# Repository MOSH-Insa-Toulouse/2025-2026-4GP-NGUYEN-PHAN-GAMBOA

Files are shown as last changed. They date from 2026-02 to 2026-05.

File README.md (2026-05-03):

# Projet : Capteur en Graphite
## Context
Ce projet a été réalisé dans le cadre du cours « Du capteur au banc de test », durant le deuxième semestre de l’année universitaire 2025–2026, au sein de la formation de 4ᵉ année en Génie Physique. Il s’appuie sur l’article scientifique « Pencil Drawn Strain Gauges and Chemiresistors on Paper » de Cheng-Wei Lin, Zhibo Zhao, Jaemyung Kim et Jiaxing Huang, qui étudie les propriétés du graphite et démontre son potentiel en tant que matériau sensible pouvant être utilisé comme capteur de déformation.

L’idée principale de ce projet est de concevoir un capteur de déformation low-tech, inspiré de cette publication, en utilisant uniquement une feuille de papier et une couche de graphite d'un crayon déposée par simple tracé.

L’objectif est d’évaluer les performances, la fiabilité de ce capteur à faible coût et de vérifier s’il peut être commercialisé.
## Sommaire
- [Context](#context)
- [Sommaire](#sommaire)
- [Principe de fonctionnement du capteur en graphite](#principe-de-fonctionnement-du-capteur-en-graphite)
- [Réalisation du projet](#réalisation-du-projet)
  - [Matériaux nécessaire](#matériaux-nécessaire)
  - [Simulation électronique sur LTSpice](#simulation-électronique-sur-ltspice)
  - [Conception PCB avec KiCad](#conception-pcb-avec-kiCad)
  - [Réalisation du Shield](#réalisation-du-shield)
  - [Code Arduino](#code-arduino)
  - [Conception application sur MIT App Inventor](#conception-application-sur-mit-app-inventor)
  - [Bancs de test](#bancs-de-test)
    - [Sensibilité](#sensibilité)
    - [Répétabilité](#répétabilité)
- [Datasheet](#datasheet)
- [Conclusion](#conclusion)

## Principe de fonctionnement du capteur en graphite
<div align="center">
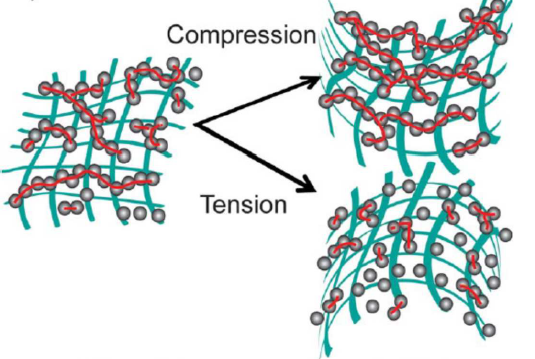
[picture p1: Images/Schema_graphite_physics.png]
  
  <br/>
  <em>Figure 1: Principe de fonctionnement du capteur graphite en traction et en compression</em>
</div>
  <br/>

La mine de crayon est déposée sur le papier de manière mécanique. Elle pénètre dans la structure poreuse du papier et forme une piste conductrice composée de particules de graphite mélangées à un liant isolant, comme l’argile. Ces particules créent un réseau conducteur à l’intérieur des fibres du papier. Quand le papier est soumis à une contrainte mécanique, ce réseau change : sous traction, les contacts entre les particules diminuent, tandis que sous compression, ils augmentent. Ces modifications provoquent alors des variations mesurables de la résistance électrique.

## Réalisation du projet
Afin d’atteindre les objectifs fixés, le travail a été divisé en deux tâches principales : 

1. la mesure de la résistance du capteur en graphite et son affichage via une interface

2. la réalisation de bancs de test pour évaluer l’efficacité de ce capteur
<div align="center">
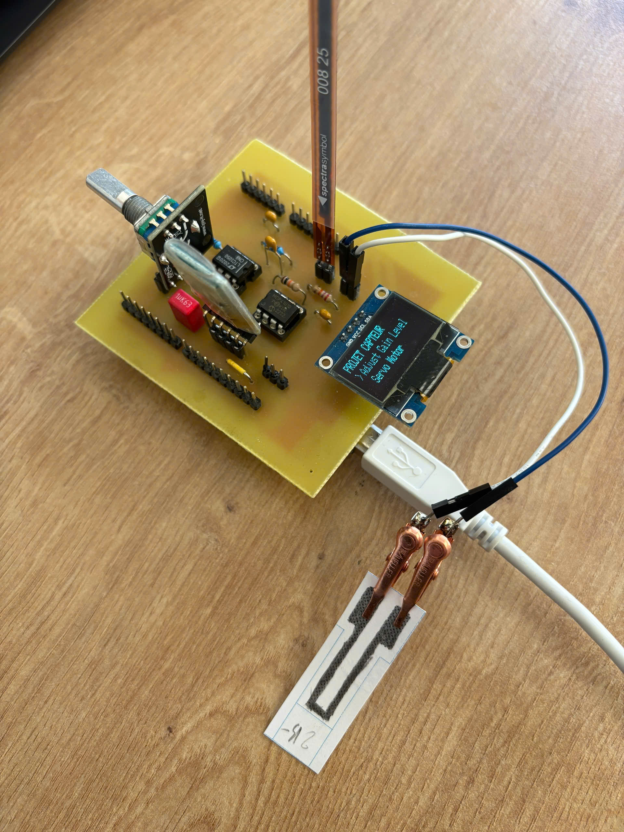
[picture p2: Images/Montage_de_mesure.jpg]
  
  <br/>
  <em>Figure 2: Montage expérimental de mesure du capteur graphite</em>
</div>

### Matériaux nécessaire
Pour réaliser le shield, nous avons besoin du matériel suivant :

* 1 carte Arduino UNO Rev 3
* 1 module Bluetooth (HC-05)
* 1 encodeur rotatif (KY-040)
* 1 écran OLED (Joy-it SBC-OLED01)
* 1 capteur de flexion commercial (Spectra Symbol Flex Sensors 005 21)
* 1 capteur en graphite fabriqués de la mine d'un crayon de papier
* 1 amplificateur (LTC1050)
* 1 potentiomètre numérique (MCP41010)
* 1 résistance 1kΩ, 1 résistance 10kΩ, 2 résistances 100kΩ et 1 résistance 27kΩ
* 3 condensateurs 100nF, 1 condensateur 1µF
* 2 supports IC pour le potentiomètre et l'amplificateur
* Pin headers (male et female)

Pour les bancs de test :
* 1 modèle 3D à diamètres variables
* 1 servomoteur (Parallax standard servo)

### Simulation électronique sur LTSpice
Dans le cas réel, la résistance du capteur en graphite est très élevée, ce qui conduit à un courant très faible, de l’ordre de 100 à 150 nA. Dans ces conditions, une mesure directe de la résistance à l’aide d’un multimètre n’est pas optimale.
Nous avons donc choisi de mesurer ce faible courant à l’aide d’un microcontrôleur. L’Arduino Uno a été retenu car il est open source, simple à utiliser, et bénéficie d’une large communauté, ce qui nous rend plus facile pour une première approche des microcontrôleurs.

En raison du courant très faible fourni par le capteur, nous avons utilisé un amplificateur transimpédance pour transformer ce courant en une tension mesurable par l’Arduino. Le gain du circuit peut être modifié simplement en changeant la valeur de la résistance R2.

Pour limiter le bruit, en particulier le bruit du réseau électrique à 50 Hz, trois filtres passe‑bas ont été ajoutés. Ces filtres permettent aussi de s’assurer que le signal en sortie du circuit est compatible avec la fréquence d’acquisition de l’Arduino.

<div align="center">
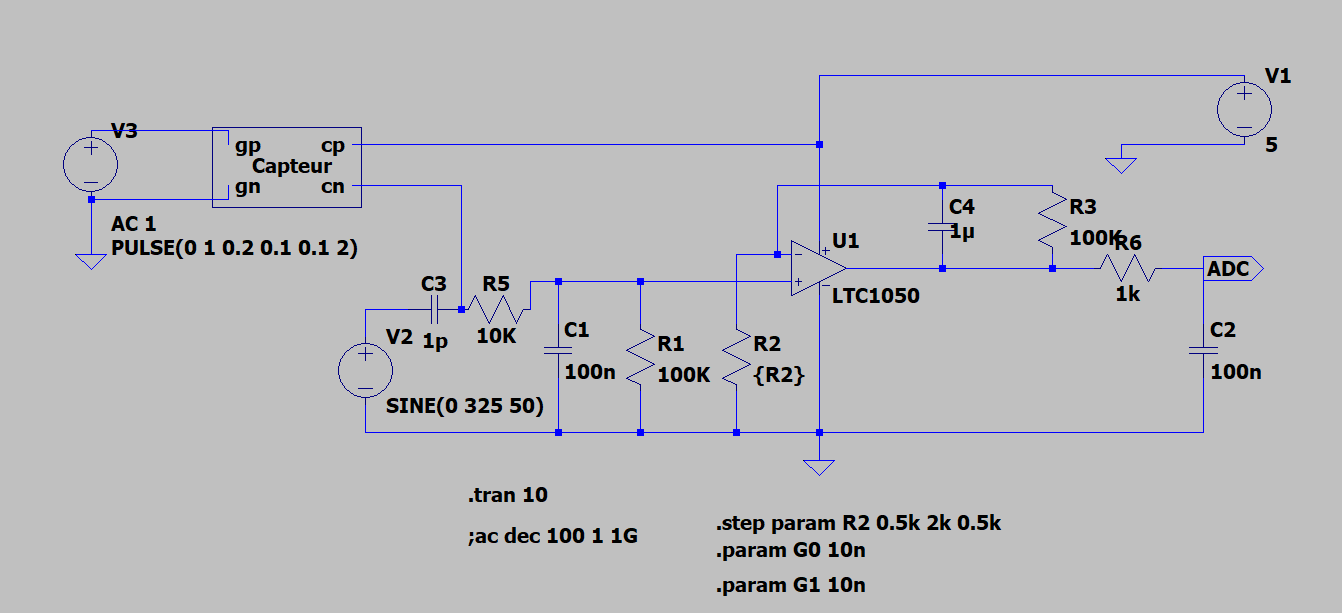
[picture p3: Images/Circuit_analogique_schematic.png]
  
  <br/>
  <em>Figure 3: Circuit d’amplification et de filtrage du signal</em>
</div>  
  <br/>

<table width="100%">
  <tr>
    <td width="50%" align="center">
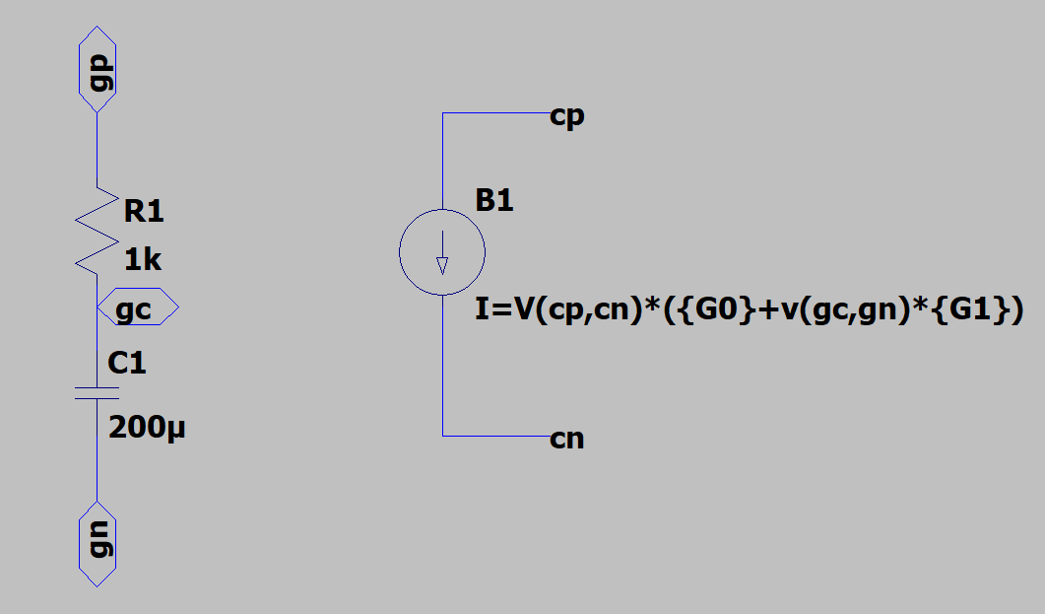
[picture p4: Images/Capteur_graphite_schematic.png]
      <br>
      <em>Figure 4: Modèle électrique du capteur graphite</em>
    </td>
    <td width="50%" align="center">
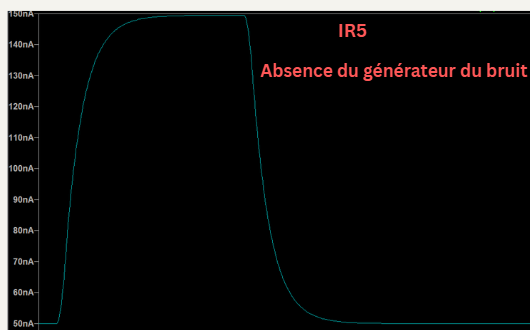
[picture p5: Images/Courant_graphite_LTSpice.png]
      <br>
      <em>Figure 5: Courant du capteur graphite simulé sous LTSpice (sans bruit)</em>
    </td>
  </tr>
</table>

Pour la simulation, le capteur graphite réel est modélisé dans LTSpice par un circuit électronique dans le figure 4, qui produit une sortie de courant d’environ 150 nA conformément à la valeur réalité (Figure 5). Le sous‑ensemble C3, R5 et le générateur V2 permet de simuler les bruits provenant de l’environnement.

<table>
  <tr>
    <td align="center">
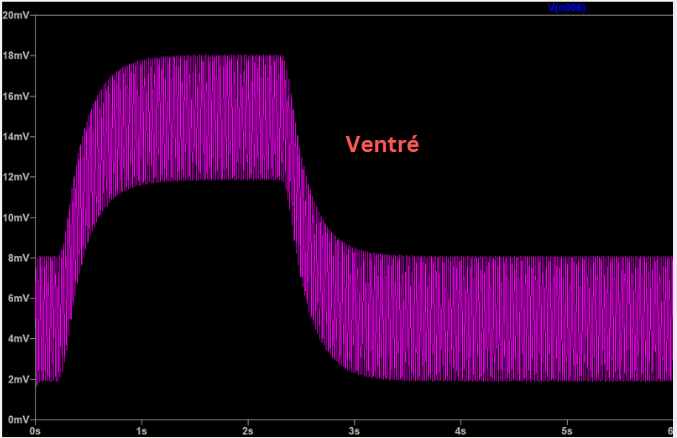
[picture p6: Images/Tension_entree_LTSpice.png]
Hình 1
      
      <br/>
      <em>Figure 6: Tension d’entrée du circuit d'amplificateur simulée sous LTSpice</em>
    </td>
    <td align="center">
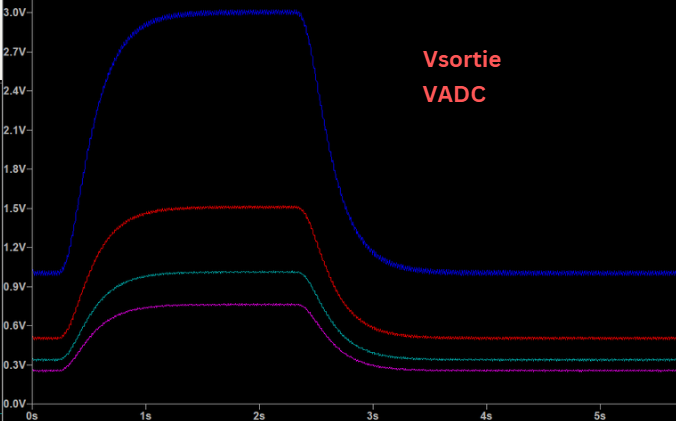
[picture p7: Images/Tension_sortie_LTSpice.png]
Hình 2
      
      <br/>
     <em>Figure 7: Tension de sortie du circuit (V_ADC) simulée sous LTSpice</em>
    </td>
  </tr>
</table>

Les simulations montrent une tension d’entrée du circuit d’environ 18 mV avant filtrage et amplification (Figure 6). En sortie, le signal est correctement amplifié et filtré, comme illustré sur la figure correspondante 7. Le niveau d’amplification obtenu dépend directement de la valeur choisie pour R2.

### Conception PCB avec KiCad
Après avoir vérifié que le circuit électronique proposé fonctionnait correctement sous LTSpice, nous avons commencé la conception du shield Arduino avec KiCad.

Le shield intègre l’ensemble des éléments nécessaires à notre projet :

- un circuit analogique pour l’amplification et le filtrage du signal du capteur graphite 
- un potentiomètre numérique pour régler le gain du signal 
- un encodeur rotatif permettant de naviguer dans les menus 
- un écran OLED pour afficher les informations et les fonctions du système 
- un module Bluetooth pour la communication avec l’application Android 
- un servomoteur utilisé dans les bancs de test 
- un capteur flex, utilisé comme référence pour comparer les performances avec le capteur graphite
<div align="center">
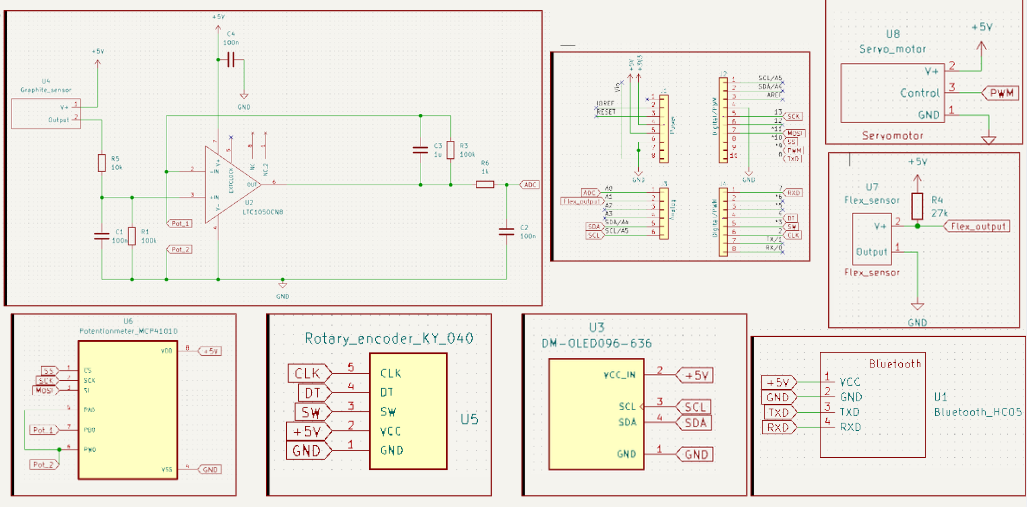
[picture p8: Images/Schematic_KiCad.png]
  
  <br/>
  <em>Figure 8: Schéma électronique global du système sous KiCad</em>
</div>  
  <br/>

Une fois tous les schémas électroniques réalisés et correctement connectés, nous avons effectué le routage du PCB. Pendant le routage, nous avons pris soin de bien connecter les masses et de tracer les pistes afin d’éviter les interférences. Enfin, un seul via sur la face avant a été utilisé pour faciliter le routage.

La dernière étape est de générer la vue 3D du shield final. Il permet de vérifier la disposition des composants, de s’assurer qu’il n’y a pas de chevauchement et que l’espace disponible est suffisant avant la fabrication du PCB.

<table>
  <tr>
    <td align="center">
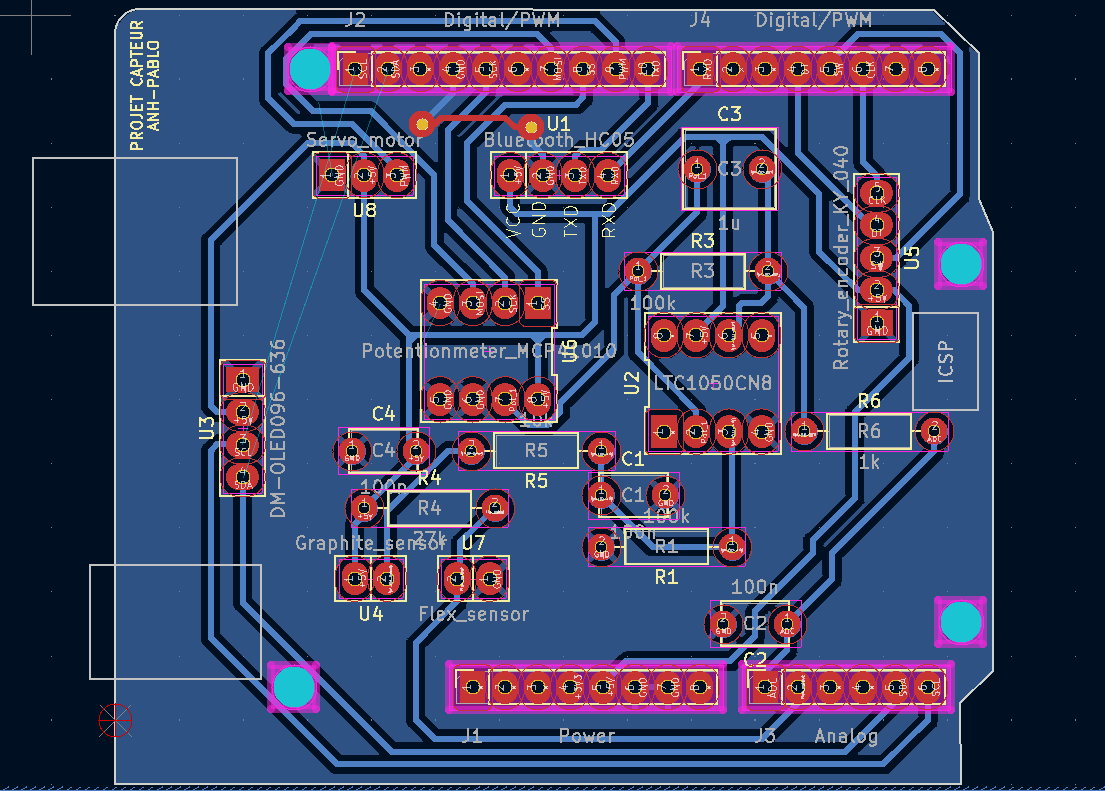
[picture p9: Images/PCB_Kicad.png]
      
      <br/>
      <em>Figure 9: Routage du PCB conçu sous KiCad </em>
    </td>
    <td align="center">
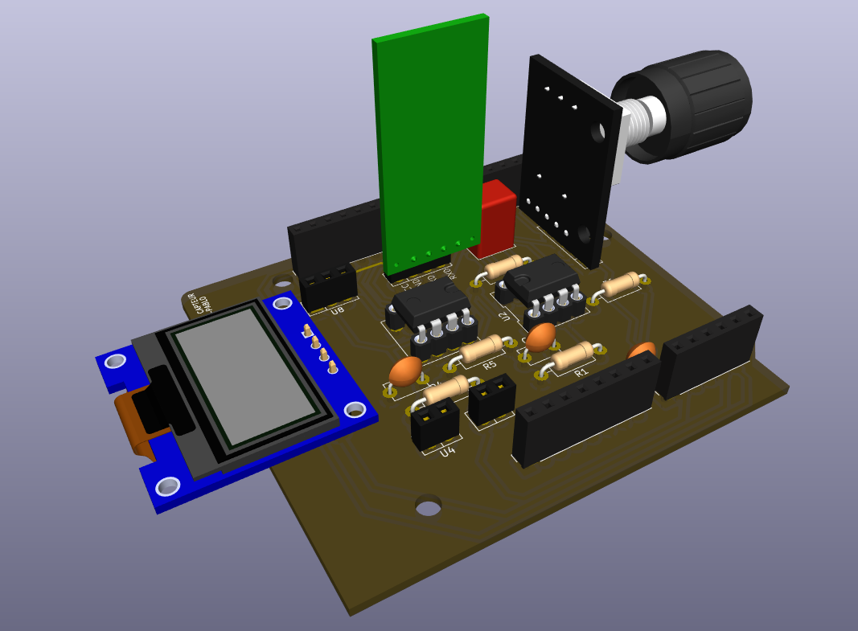
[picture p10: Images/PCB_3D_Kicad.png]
      
      <br/>
     <em>Figure 10: Vue 3D du PCB conçu sous KiCad</em>
    </td>
  </tr>
</table>

### Réalisation du Shield
Après avoir vérifié que le routage du PCB ne présentait aucune erreur, le shield a été fabriqué avec l’aide de Cathy, enseignante du département de Génie Physique.
Une fois le PCB imprimé, nous avons procédé à la mise en place des composants électroniques, puis à leur soudure sur la carte.
<table width="100%">
  <tr>
    <td width="50%" align="center">
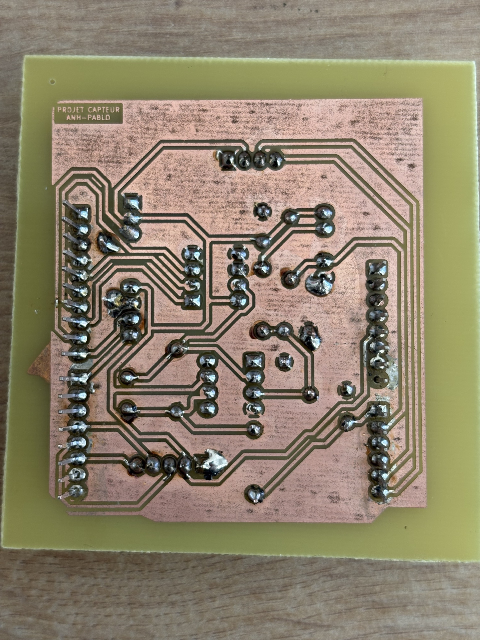
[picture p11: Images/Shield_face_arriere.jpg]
      <br>
      <em>Figure 11: Face arrière du PCB</em>
    </td>
    <td width="50%" align="center">
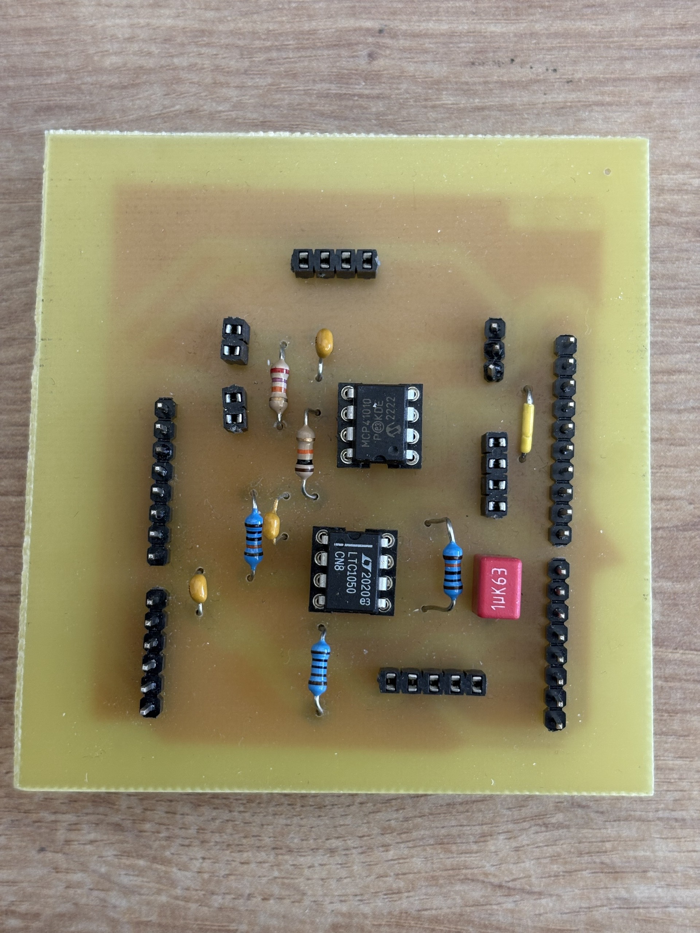
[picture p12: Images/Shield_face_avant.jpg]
      <br>
      <em>Figure 12: Face avant du PCB </em>
    </td>
  </tr>
</table>

### Code Arduino
Nous avons développé un programme sous Arduino IDE.  Dans le code, nous avons ajouté les librairies Adafruit_SSD1306 pour piloter l'écran OLED et SoftwareSerial pour le Bluetooth HC-05. Pour rendre le code plus clair et mieux organisé, le programme Arduino est divisé en plusieurs fichiers :

* Le fichier "menu_OLED" est utilisé pour contrôler le potentiomètre numérique donc régler le gain.
* Le fichier "digipot" gère l’affichage sur l’écran OLED et la lecture de l’encodeur rotatif.
* Le fichier principal (main) "capteur_projet" s’occupe du module Bluetooth, du servomoteur, et contient les fonctions setup et loop.

Ce programme permet : 
* de sélectionner le niveau d’amplification du signal
* de contrôler un servomoteur
* de communiquer avec une application Android grâce à un module Bluetooth intégré au shield, permettant ainsi l’échange de données entre le capteur et l’interface mobile

Ces deux premières fonctionnalités sont pilotées via un écran OLED pour l’affichage et un encodeur rotatif utilisé pour la navigation et la sélection dans les menus.

<div align="center">
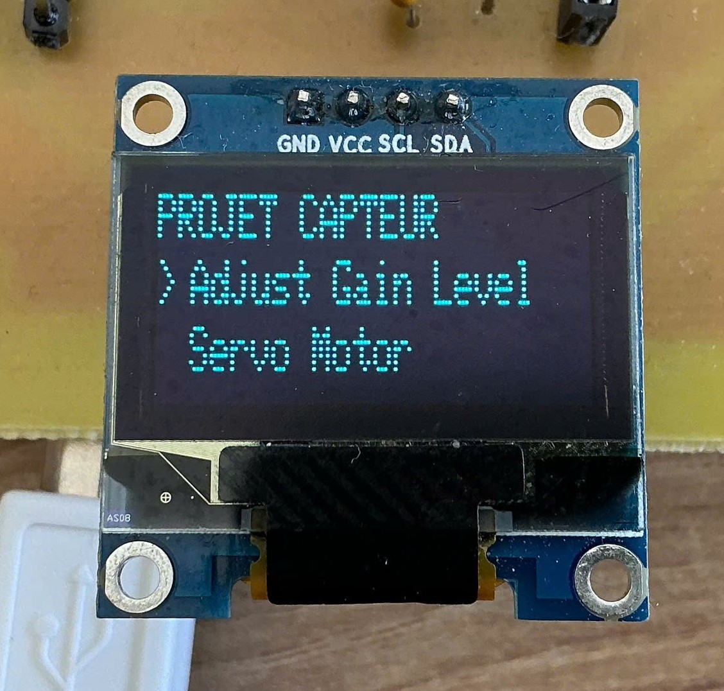
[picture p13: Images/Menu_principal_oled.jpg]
  
  <br/>
  <em>Figure 13: Menu principal affiché sur l’écran OLED</em>
</div> 
  <br/>
<div align="center">
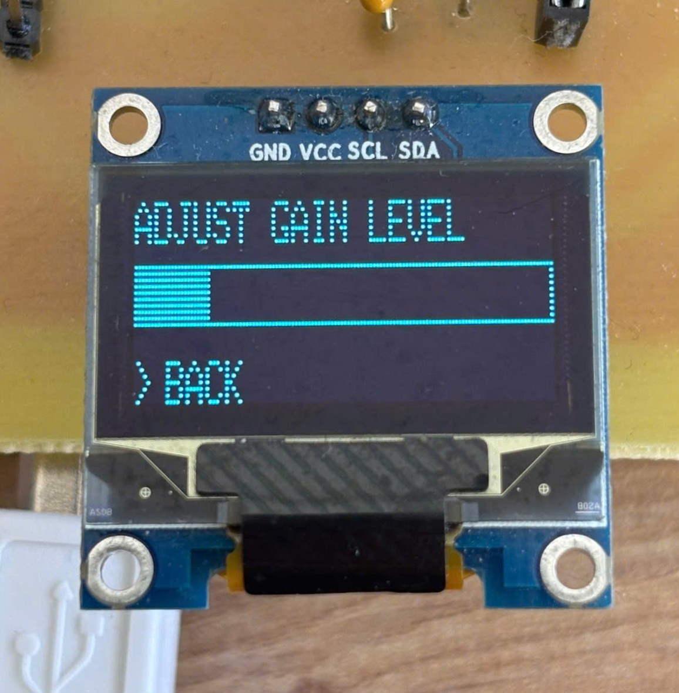
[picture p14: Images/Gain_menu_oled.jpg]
  
  <br/>
  <em>Figure 14: Menu de réglage du gain affiché sur l’écran OLED</em>
</div>
  <em>Il suffit d’appuyer sur l’encodeur pour revenir au menu principal</em>
  
  <br/>
<table>
  <tr>
    <td align="center">
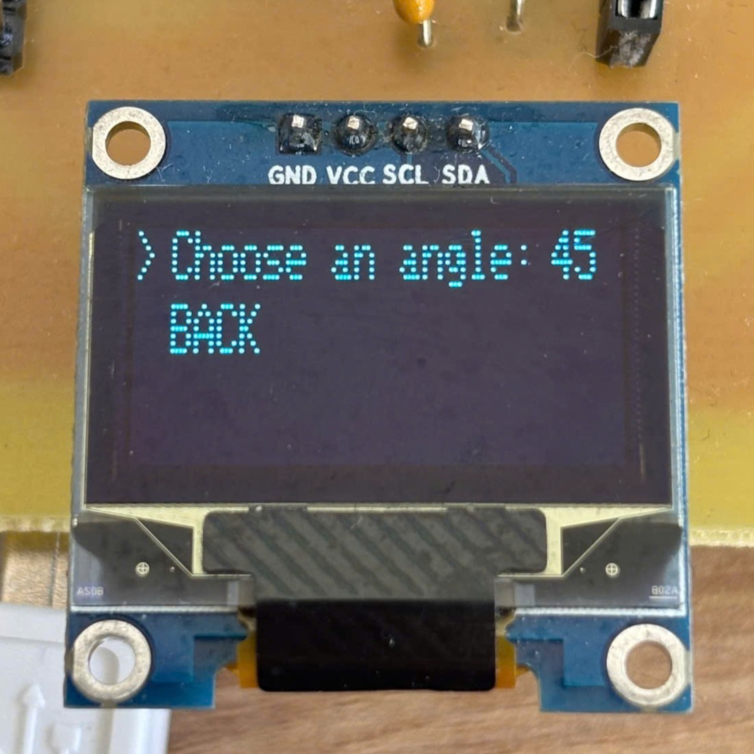
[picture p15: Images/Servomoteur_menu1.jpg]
      
      <br/>
      <em>Figure 15: Menu de sélection de l’angle du servomoteur affiché sur l’écran OLED</em>
    </td>
    <td align="center">
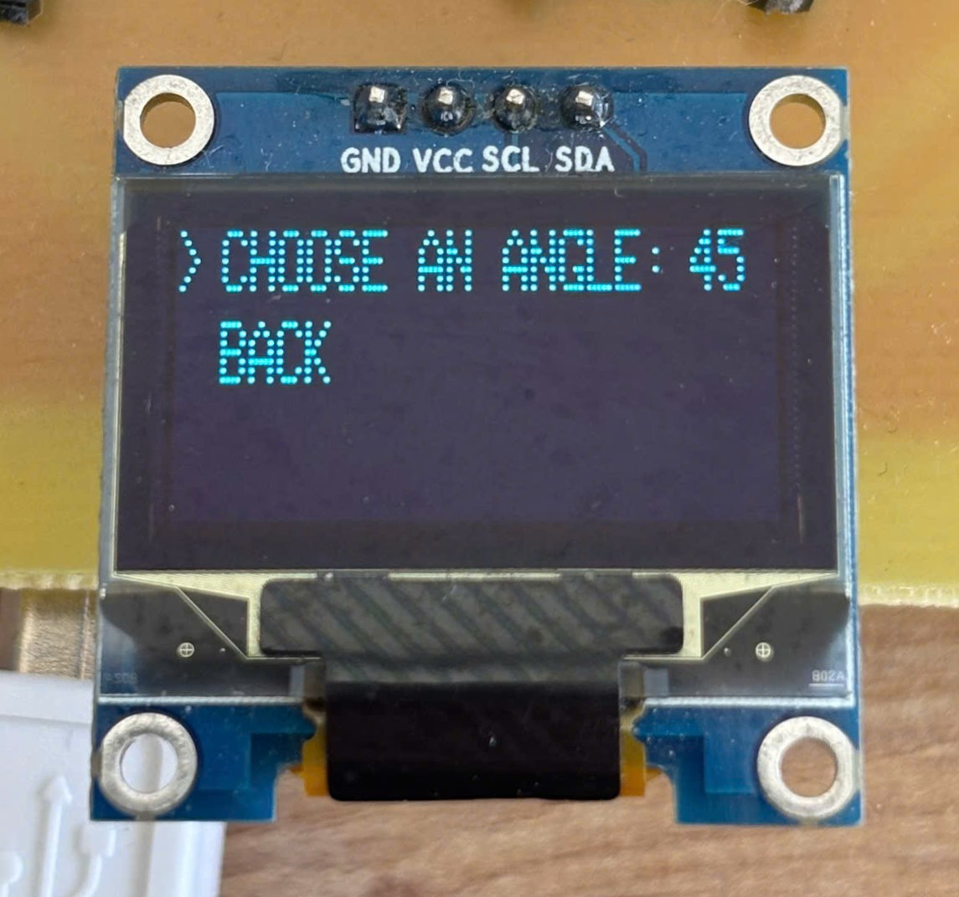
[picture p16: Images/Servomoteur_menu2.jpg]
      
      <br/>
     <em>Figure 16: Menu de sélection de l’angle du servomoteur affiché sur l’écran OLED</em>
    </td>
    <td align="center">
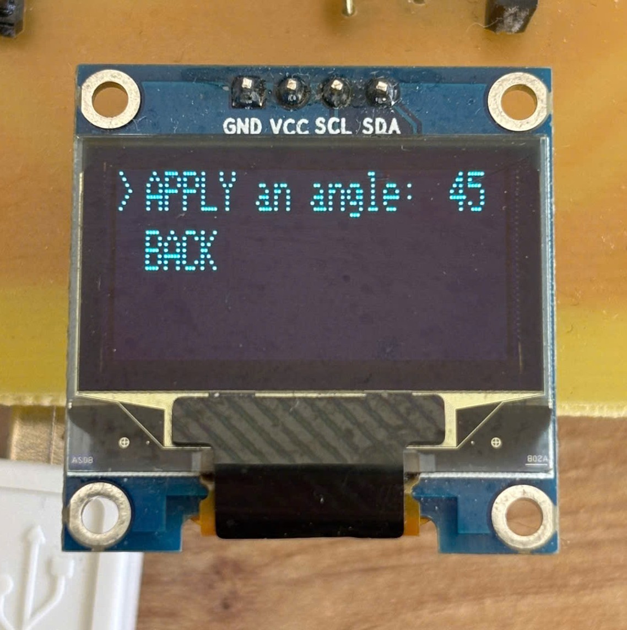
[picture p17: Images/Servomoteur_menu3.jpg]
      
      <br/>
      <em>Figure 17: Menu d'application de l’angle du servomoteur affiché sur l’écran OLED</em>
    </td>
  </tr>
</table>

Lorsque l’utilisateur entre dans le menu du servomoteur, l’écran de la figure 15 s’affiche.
En appuyant sur l’encodeur, il est possible de sélectionner un angle : le texte « Choose an angle » passe en majuscules (Figure 16).
Un nouvel appui sur l’encodeur permet d’appliquer l’angle sélectionné au servomoteur, et le mot « APPLY » apparaît en majuscules (Figure 17).
La sortie du menu servomoteur s’effectue en cliquant deux fois de suite sur l’encodeur rotatif.

Concernant la fonctionnalité du code pour communiquer avec l'application Android, en fonction des commandes reçues depuis l’application via module Bluetooth, le programme Arduino peut renvoyer à l’application :
* soit en continu (chaque 100 miliseconds) la valeur de la résistance du capteur en graphite ainsi que la tension en sortie du circuit d’amplification (tension ADC) 
* soit de manière ponctuelle la résistance du capteur en graphite
* ou de manière ponctuelle la résistance du flex sensor

Pour obtenir la valeur de la résistance du capteur, le code Arduino commence par convertir la lecture analogique (comprise entre 0 et 1023) en une tension comprise entre 0 et 5 V.
La résistance du capteur en graphite et du capteur flex est ensuite calculée à partir de cette tension en utilisant la formule suivante :

* $R_{\text{graphite}} = \left(1 + \frac{R_3}{R_2}\right) \cdot R_1 \cdot \left(\frac{V_{\text{CC}}}{V_{\text{ADCgraphite}}}\right) - R_1 - R_5$

* $R_{\text{flex}} = R_{\text{Division}} \cdot \frac{V_{\text{flex}}}{V_{\text{CC}} - V_{\text{ADCflex}}}$
### Conception application sur MIT App Inventor
Pour assurer la communication avec l’utilisateur et l’affichage des données, une application Android a été développée à l’aide de MIT App Inventor.

Cette application communique avec l’Arduino via une connexion Bluetooth et intègre deux fonctionnalités principales :

* Affichage en temps réel de la variation de la résistance du capteur graphite lorsqu’une déformation est appliquée. La tension ADC est également affichée afin de permettre à l’utilisateur d’ajuster le gain lorsque le signal est saturé ou trop faible. (Figure 19)
* Mesure ponctuelle de la résistance du capteur sélectionné lors de l’appui sur le bouton Measure. L’utilisateur peut saisir la valeur de référence du capteur à l’état non déformé, puis l’application calcule automatiquement le rapport ΔR/R0. (Figure 20)

<div align="center">
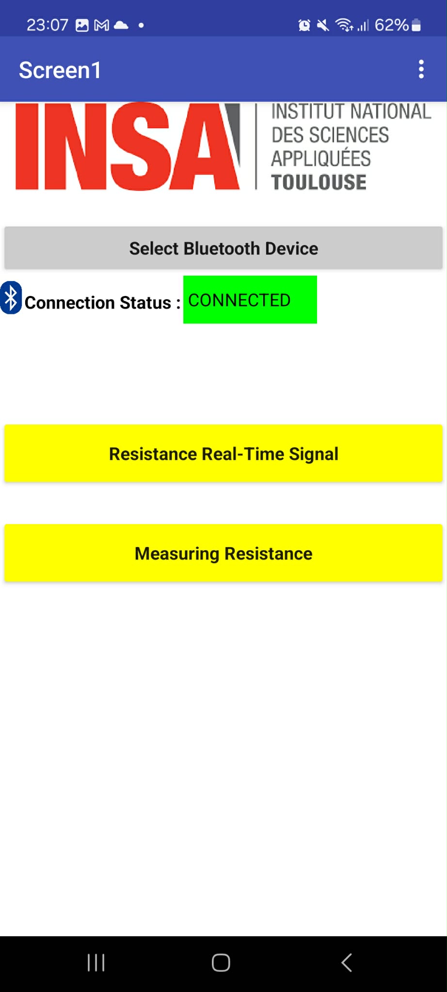
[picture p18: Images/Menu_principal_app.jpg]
  
  <br/>
  <em>Figure 18: Interface principale de l’application Android</em>
</div>  
  <br/>

<p align="center">
  
  <br/>
  <em>Figure 19: Démonstration de la variation de résistance du capteur en graphite sous déformation sur l'application Android</em>
</p>

<div align="center">
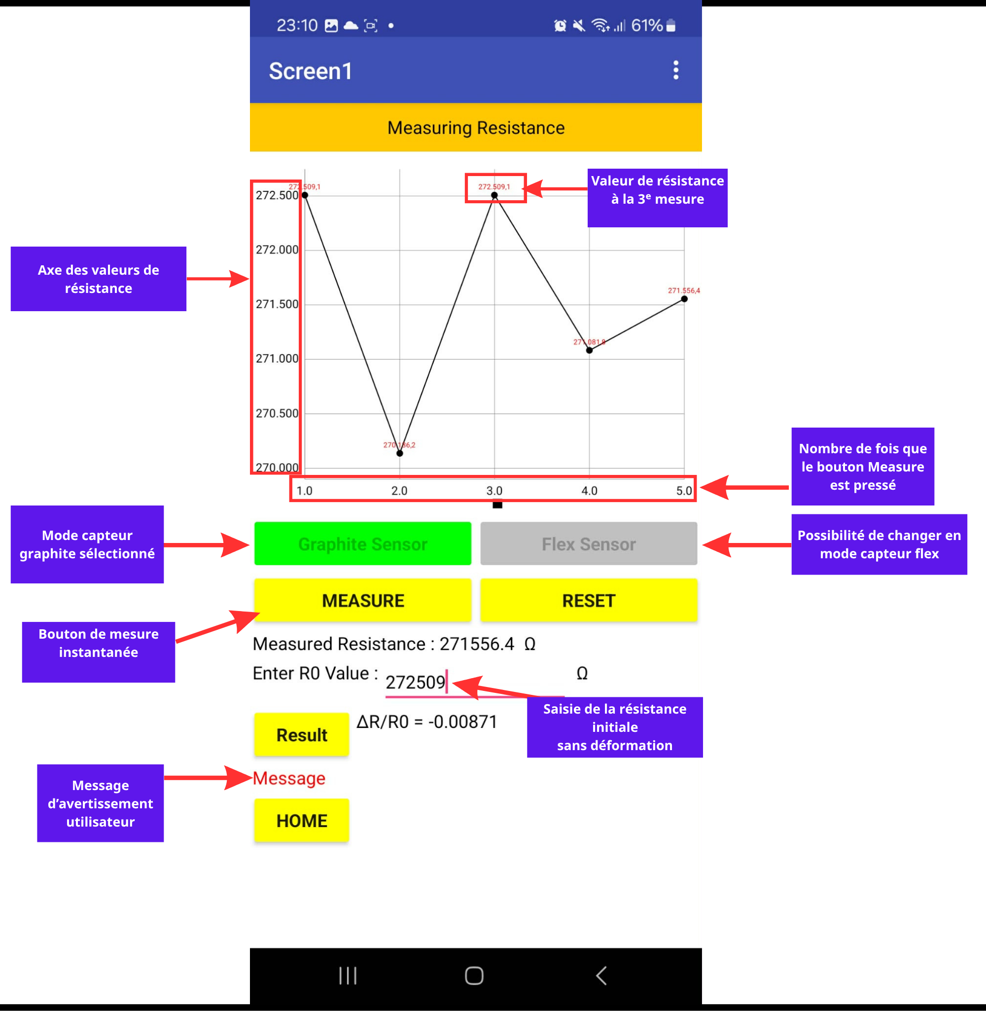
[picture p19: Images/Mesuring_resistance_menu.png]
  
  <br/>
  <em>Figure 20: Interface de mesure de la résistance dans l’application Android</em>
</div>

L’application peut être téléchargée via ce code [QR](Application%20Android/QR_code_app.png).

### Bancs de test
Afin d’étudier les caractéristiques et d’évaluer les performances du capteur en graphite, deux bancs de test ont été mis en place.
Ces bancs permettent d’analyser en particulier la sensibilité et la rentabilité du capteur, en comparaison avec un capteur flex commercial.
#### Sensibilité
Pour mesurer la sensibilité des capteurs, un modèle mécanique imprimé en 3D a été utilisé.

<div align="center">
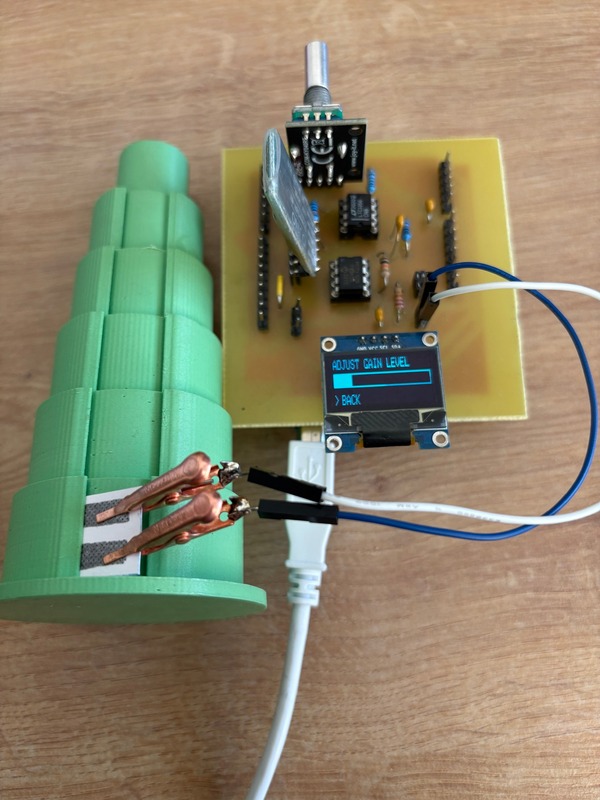
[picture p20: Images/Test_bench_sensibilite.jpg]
  
  <br/>
  <em>Figure 21: Protocole de banc de test de sensibilité</em>
</div>

Ce modèle est constitué de plusieurs arcs de cercle de rayons différents, chaque rayon correspondant à un niveau de déformation différent appliqué au capteur.

Le capteur est successivement placé sur chaque arc, ce qui permet d’imposer une déformation contrôlée, aussi bien en traction (tension) qu’en compression.
La même procédure est appliquée au capteur graphite et au capteur flex, afin de permettre une comparaison directe.
Pour le capteur graphite, les mesures ont été réalisées avec différents types de graphite : HB, 2B, 4B et 6B.
Les résultats obtenus sont présentés sur les figures suivantes, montrant l’évolution du rapport ΔR/R0 en fonction de la déformation, en traction et en compression.
<div align="center">
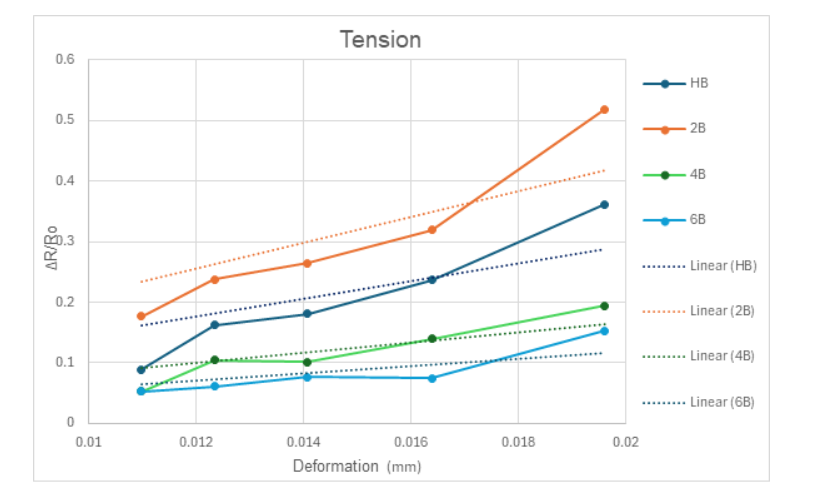
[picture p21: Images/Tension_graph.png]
  
  <br/>
  <em>Figure 22: Variation du rapport ΔR/R0 en fonction de la déformation en tension pour différents types de graphite et le capteur flex</em>
</div>
  <br/>

<div align="center">
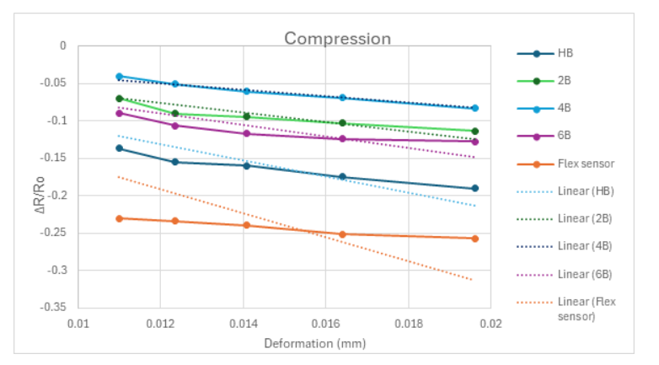
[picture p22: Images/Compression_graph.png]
  
  <br/>
  <em>Figure 23: Variation du rapport ΔR/R0 en fonction de la déformation en compression pour différents types de graphite et le capteur flex</em>
</div>

##### Résultat
<div align="center">
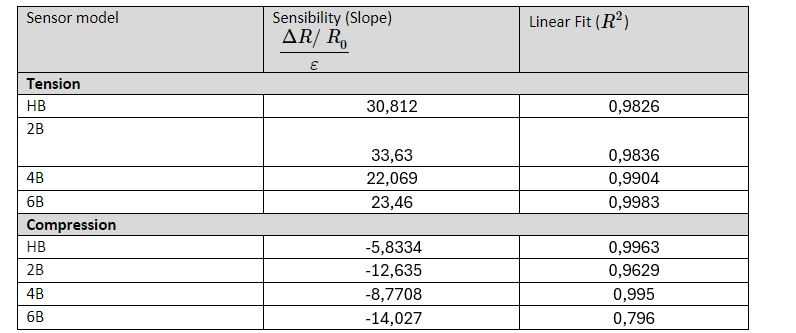
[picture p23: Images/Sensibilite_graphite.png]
  
  <br/>
  <em>Figure 24: Résultats de sensibilité des capteurs graphite (HB, 2B, 4B, 6B)</em>
  
  <br/>
  <em>Figure 25: Résultats de sensibilité du capteur flex en traction et en compression</em>
</div>  

Les mesures montrent une relation globalement linéaire entre la variation de résistance ΔR/R0 et la déformation appliquée, aussi bien en traction qu’en compression. Cela indique que les capteurs réagissent de manière cohérente aux déformations imposées.

Pour le capteur graphite, le graphite de type 2B présente la sensibilité la plus élevée, aussi bien en traction qu’en compression, comparé aux graphites HB, 4B et 6B. En comparaison avec le capteur flex :

* en traction, la sensibilité du capteur flex est supérieure à celle du graphite 2B.
* en compression, la sensibilité du capteur flex est très faible, ce qui est cohérent avec le fait que ce type de capteur est principalement conçu pour fonctionner en traction, comme spécifié par le fabricant.
#### Répétabilité
Pour vérifier la répétabilité du capteur, nous avons mis en placeun banc de test simple.
Comme montré sur les figures, un servomoteur est relié au capteur à l’aide d’un petit bâton en bois. L’ensemble du montage est fixé avec de la colle afin de limiter les déplacements parasites pendant les mesures.
Le servomoteur applique successivement un angle de 0° puis de 120° au capteur. Ce cycle est répété cinq fois de suite.
Ce test est réalisé avec un capteur graphite 2B, car ce type de graphite a montré la meilleure sensibilité lors des essais précédents. Le même protocole est également appliqué au capteur flex afin de pouvoir comparer les résultats.
<div align="center">
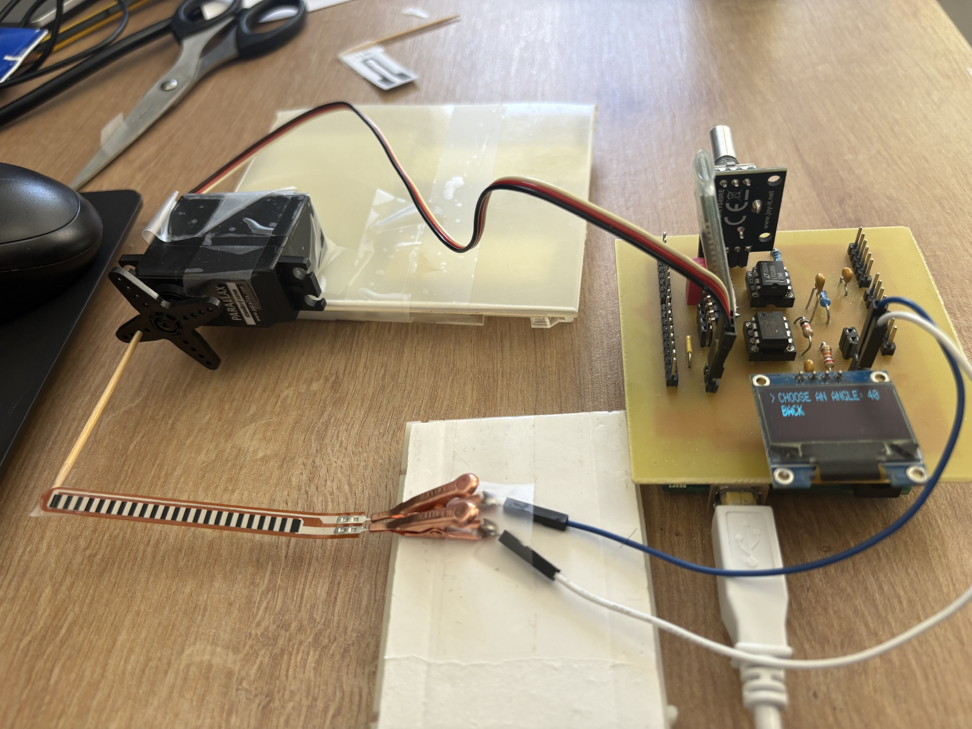
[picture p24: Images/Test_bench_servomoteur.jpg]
  
  <br/>
  <em>Figure 26: Protocole de banc de test de répétabilité avec servomoteur</em>
</div>

##### Résultat

<table width="100%">
  <tr>
    <td width="50%" align="center">
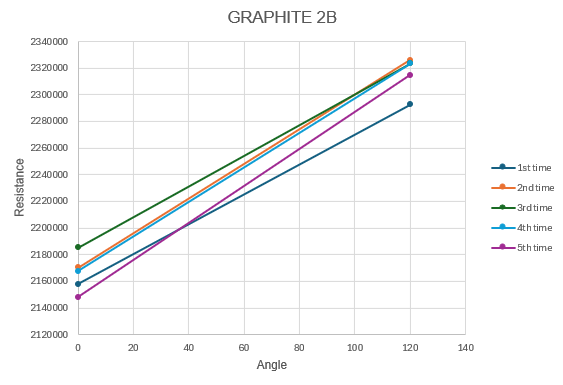
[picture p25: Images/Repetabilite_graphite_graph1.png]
      
      <br/>
      <em>Figure 27: Répétabilité du capteur graphite – mesures répétées 5 fois</em>
    </td>
    <td width="50%" align="center">
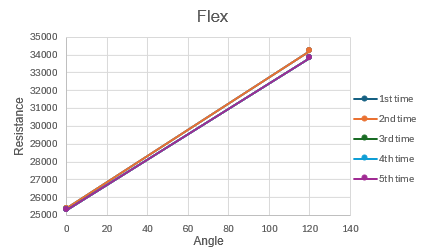
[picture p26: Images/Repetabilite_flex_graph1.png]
      
      <br/>
      <em>Figure 28: Répétabilité du capteur flex – mesures répétées 5 fois</em>
    </td>
  </tr>
</table>

<table>
  <tr>
    <td align="center">
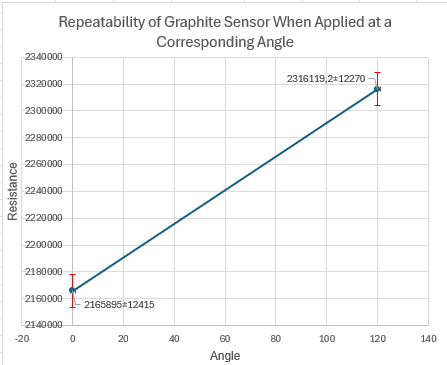
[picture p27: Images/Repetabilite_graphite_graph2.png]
      
      <br/>
      <em>Figure 29: Répétabilité du capteur graphite 2B – valeur moyenne et écart‑type</em>
    </td>
    <td align="center">
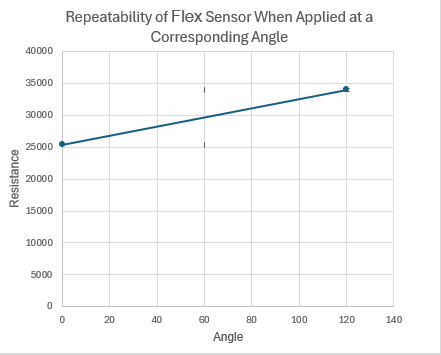
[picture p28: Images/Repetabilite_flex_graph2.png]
      
      <br/>
     <em>Figure 30: Répétabilité du capteur flex – valeur moyenne et écart‑type</em>
    </td>
  </tr>
</table>

Les figures 27 et 28 montrent la valeur de la résistance mesurée pour chaque angle, avec une courbe correspondant à chaque répétition du test.
Les figures 29 et 30 présentent la valeur moyenne de la résistance pour chaque angle. Les barres d’erreur représentent l’écart‑type calculé à partir des différentes mesures.
Pour le capteur flex, la répétabilité est très bonne : les courbes sont presque superposées et l’écart‑type est très faible, au point d’être difficilement visible sur le graphique.
Pour le capteur graphite 2B, on observe un léger décalage entre les différentes répétitions. La répétabilité est donc un peu moins bonne que celle du capteur flex. Toutefois, l’écart entre les mesures reste faible, de l’ordre de 0,5 % de la valeur moyenne.

### Datasheet
La fiche technique du capteur est disponible dans le dossier [Datasheet_capteur_graphite.pdf](Datasheet/Datasheet_capteur_graphite.pdf) du projet.
### Conclusion
Après l’analyse des résultats obtenus lors des bancs de test, nous constatons que le capteur graphite de type 2B présente une bonne sensibilité, proche de celle du capteur flex. De plus, les écarts liés à la répétabilité restent limités et ne sont pas trop importants.

Cependant, malgré ces résultats encourageants, ce capteur graphite simple présente plusieurs inconvénients qui rendent sa commercialisation difficile dans sa forme actuelle.
- Le capteur est fragile. Le support en papier et la couche de graphite peuvent se détériorer après plusieurs utilisations, ce qui réduit la précision des mesures.
- La quantité de graphite déposée sur le papier peut varier à cause de l’environnement, comme la manipulation par l’utilisateur, la température ou l’humidité. Cela entraîne une variation de la résistance initiale au cours du temps.
- Il est également difficile de reproduire exactement le même capteur, car le dépôt manuel du graphite ne permet pas de contrôler précisément la quantité déposée.
- Le contact électrique a une grande influence sur les mesures : selon la position des contacts sur le capteur, les valeurs obtenues peuvent changer, ce qui limite la précision des tests.

À partir de ces limites, nous proposons plusieurs solutions d’amélioration suivantes:
- Utiliser un support plus solide et résistant que le papier, moins sensible aux déformations.
- Ajouter un film de protection pour limiter l’influence de l’environnement sur le graphite.
- Automatiser le dépôt du graphite afin d’assurer une quantité constante de graphite sur papier.
- Encapsuler le capteur avec des contacts électriques fixes pour améliorer la répétabilité et la fiabilité des mesures.

En conclusion, ce projet montre qu’un capteur de déformation à base de graphite peut être une solution simple et peu coûteuse, mais qu’il nécessite encore des améliorations pour être utilisé de manière fiable et envisager une commercialisation.
### Contact
- NGUYEN Phan-Xuan-Anh : pnguye@insa-toulouse.fr
- GAMBOA-SAURY Pablo-David : pgamboa-saur@insa-toulouse.fr

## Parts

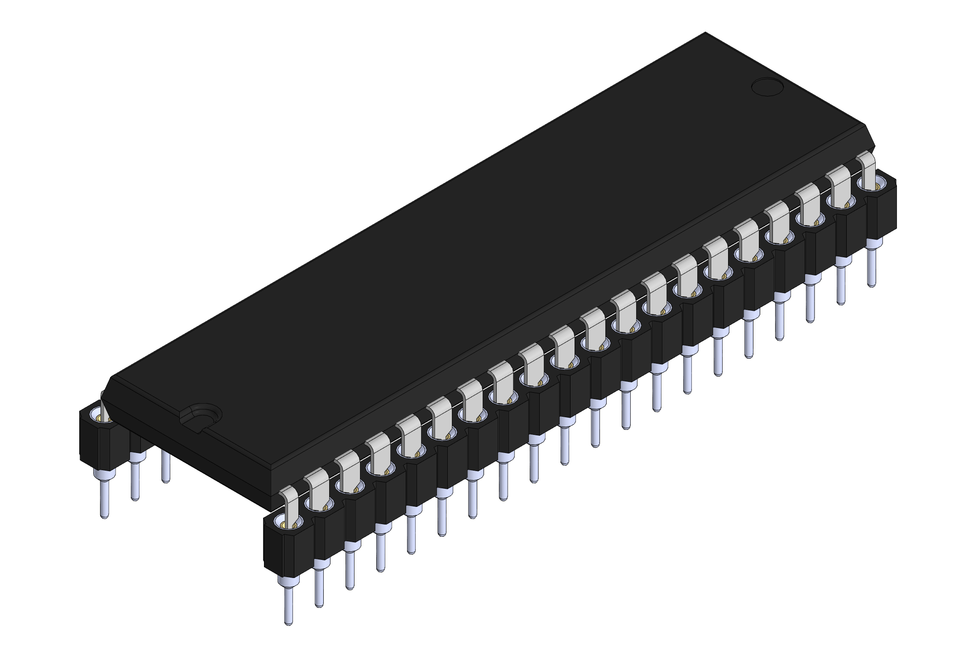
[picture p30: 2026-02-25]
KiCad/KiCAD_1/Component library/Dip_ic_on_sip_socket/DIP on SCSL.png

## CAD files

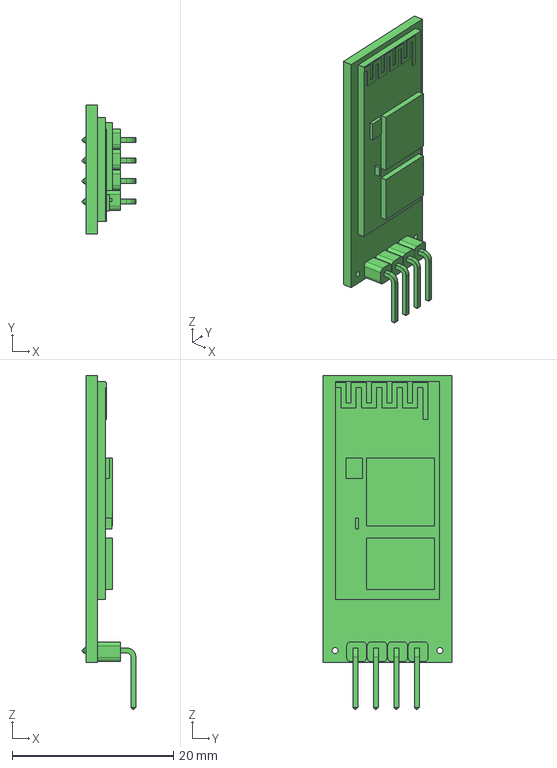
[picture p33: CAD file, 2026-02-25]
KiCad/KiCAD_1/Component library/Bluetooth_HC_05/HC-05 Bluetooth Module.stp
6.68 x 16.0 x 41.4 mm

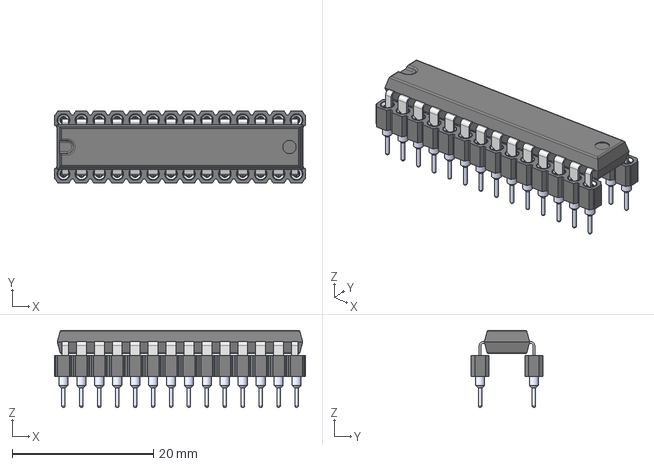
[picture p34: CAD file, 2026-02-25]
KiCad/KiCAD_1/Component library/Dip_ic_on_sip_socket/models3d/DIP/DIP-28 on SCSL-14 x2.step
35.6 x 10.2 x 10.9 mm
SCSL x 2
DIP

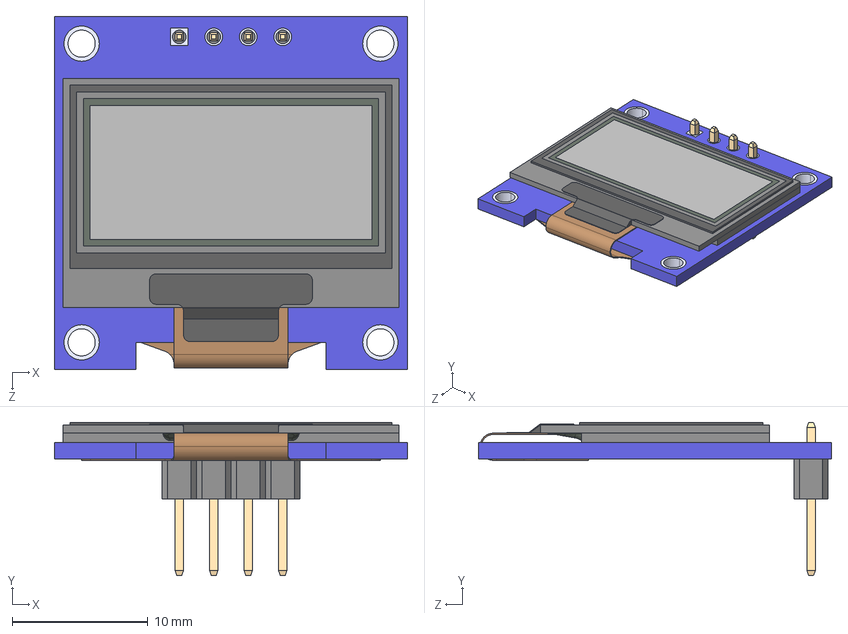
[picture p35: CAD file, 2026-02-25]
KiCad/KiCAD_1/Component library/DM_OLED_096_636/DM-OLED096-636.step
26.0 x 11.3 x 26.0 mm
DM-OLED096-636_Module
DM-OLED096-636_Panel

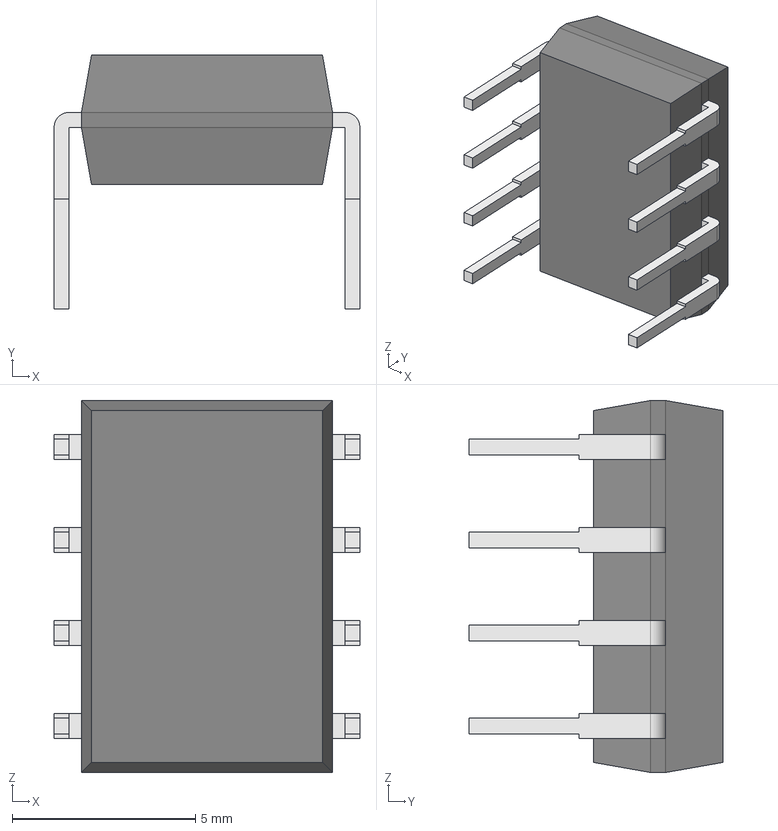
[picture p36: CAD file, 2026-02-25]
KiCad/KiCAD_1/Component library/LTC1050CN8/LTC1050CN8_PBF.step
8.35 x 6.93 x 10.2 mm
Body001 (Mirror #1) x 5

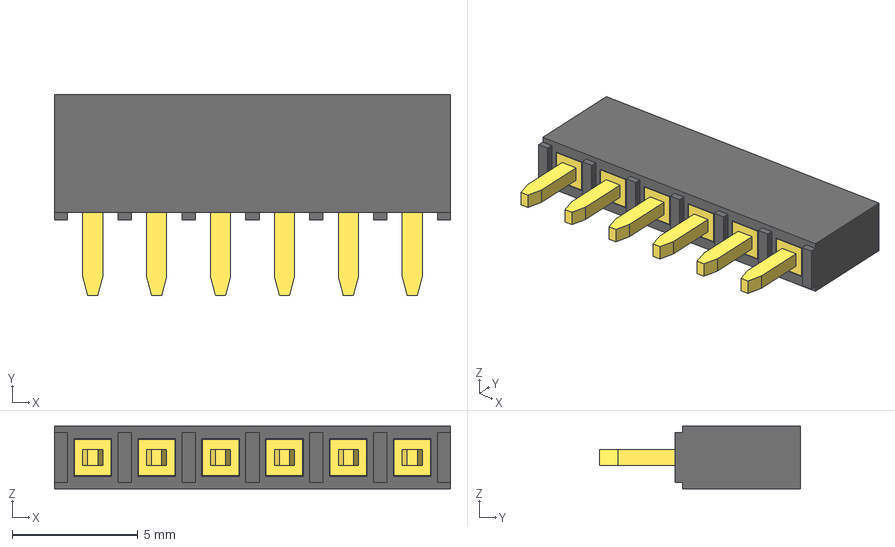
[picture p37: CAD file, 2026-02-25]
KiCad/KiCAD_1/Component library/Pin_header_female_2_54mm/6-Pin Header - Female - 2.54mm.step
15.7 x 8.00 x 2.50 mm

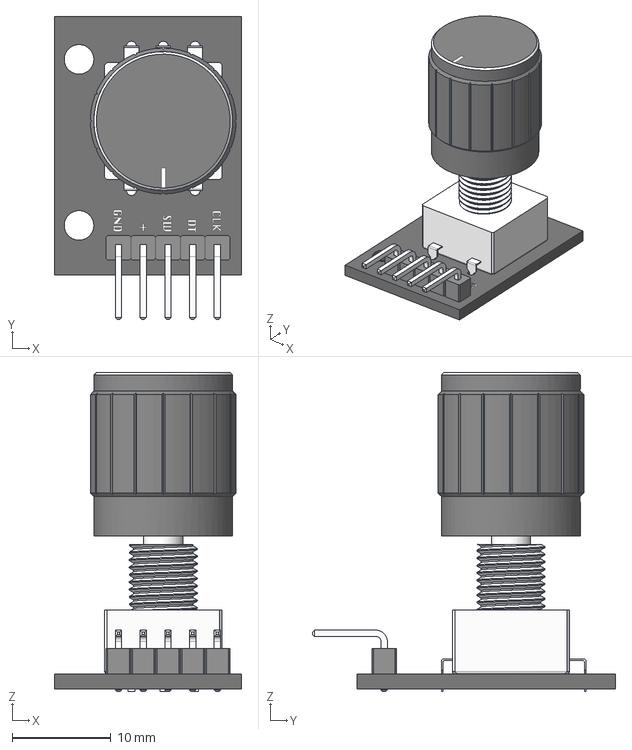
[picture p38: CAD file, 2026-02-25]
KiCad/KiCAD_1/Component library/Rotary_encoder_KY_040/Rotary Encoder - KY-040.step
19.0 x 30.8 x 32.4 mm

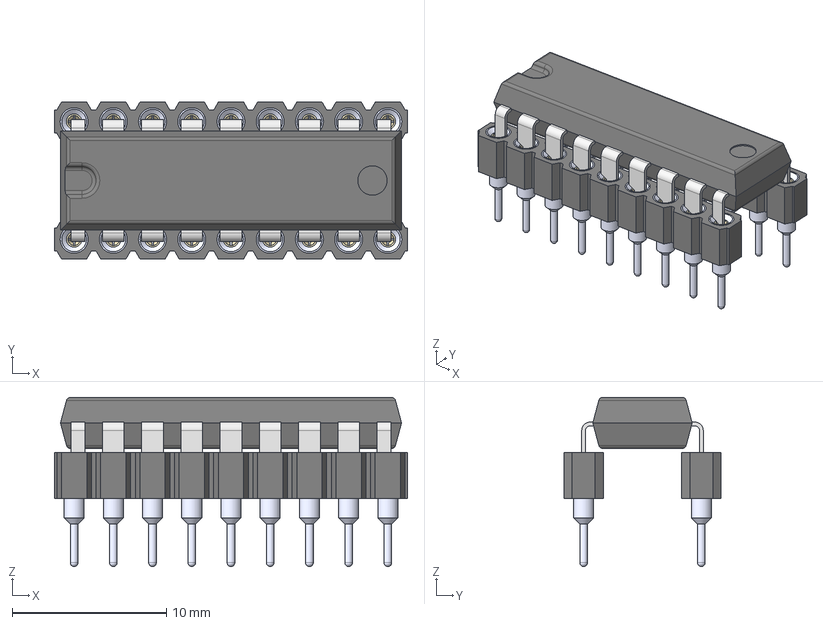
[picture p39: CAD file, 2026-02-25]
KiCad/KiCAD_1/Component library/Dip_ic_on_sip_socket/models3d/DIP/DIP-18 on SCSL-9 x2.step
22.9 x 10.2 x 10.9 mm
SCSL x 2
DIP

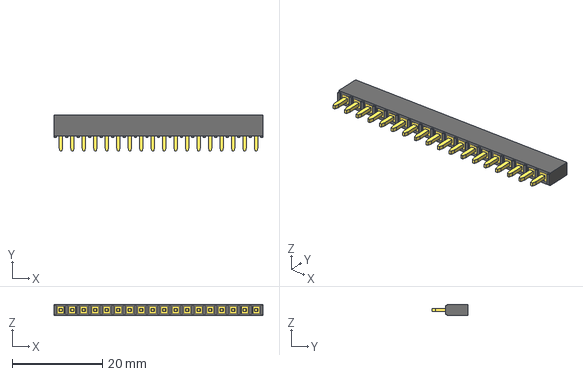
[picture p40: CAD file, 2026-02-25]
KiCad/KiCAD_1/Component library/Pin_header_female_2_54mm/18-Pin Header - Female - 2.54mm.step
46.2 x 8.00 x 2.50 mm

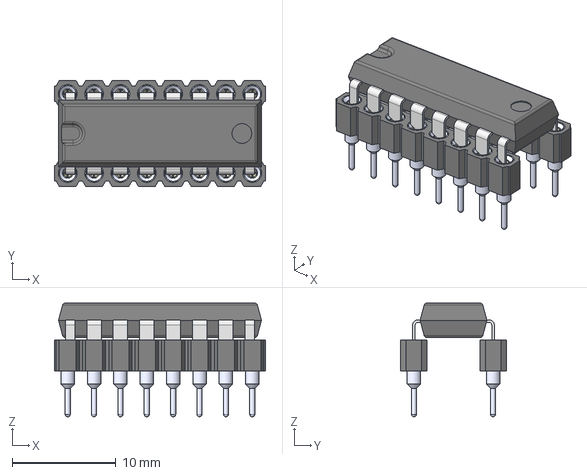
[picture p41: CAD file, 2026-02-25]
KiCad/KiCAD_1/Component library/Dip_ic_on_sip_socket/models3d/DIP/DIP-16 on SCSL-8 x2.step
20.3 x 10.2 x 10.9 mm
SCSL x 2
DIP

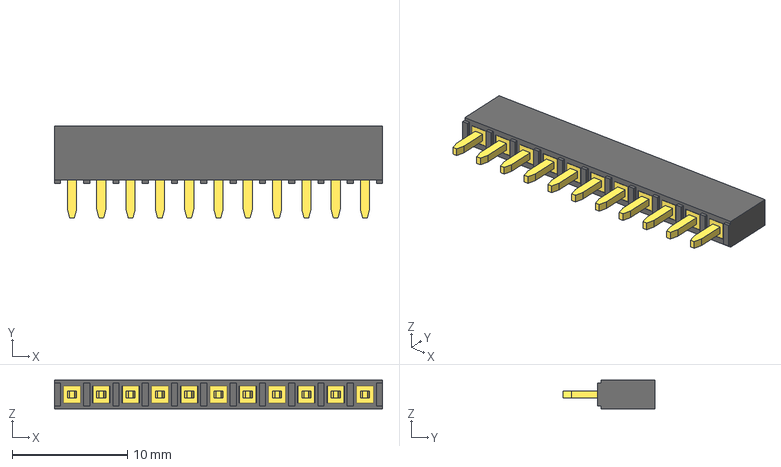
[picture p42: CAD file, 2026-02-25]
KiCad/KiCAD_1/Component library/Pin_header_female_2_54mm/11-Pin Header - Female - 2.54mm.step
28.4 x 8.00 x 2.50 mm

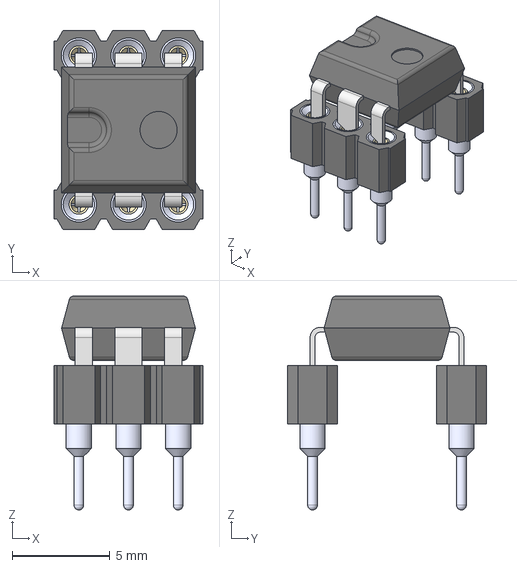
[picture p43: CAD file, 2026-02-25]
KiCad/KiCAD_1/Component library/Dip_ic_on_sip_socket/models3d/DIP/DIP-6 on SCSL-3 x2.step
7.62 x 10.2 x 10.9 mm
SCSL x 2
DIP

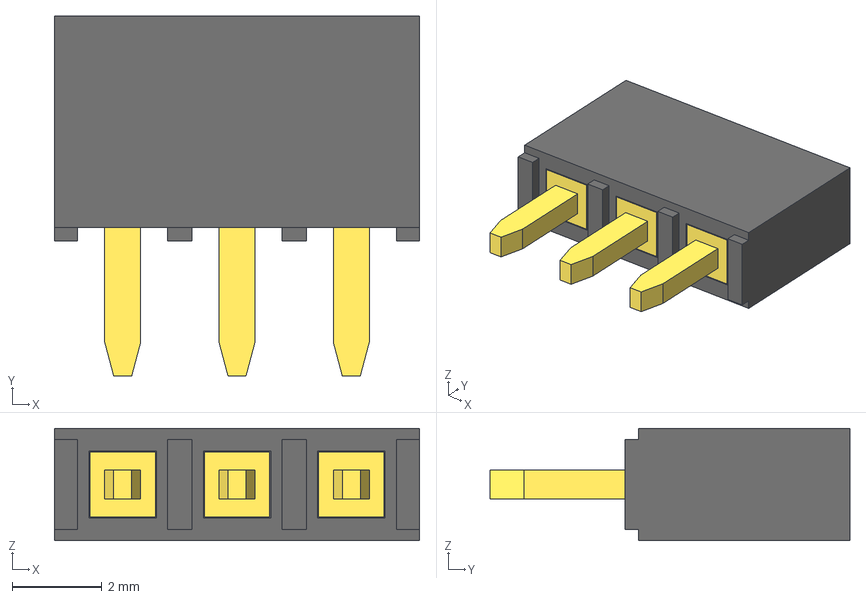
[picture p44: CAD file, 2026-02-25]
KiCad/KiCAD_1/Component library/Pin_header_female_2_54mm/3-Pin Header - Female - 2.54mm.step
8.12 x 8.00 x 2.50 mm

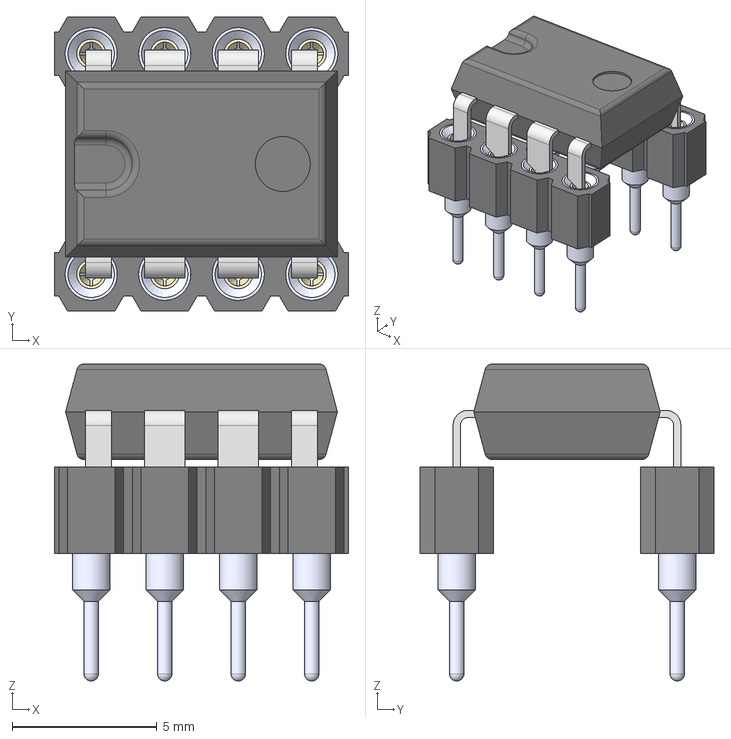
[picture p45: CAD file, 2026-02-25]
KiCad/KiCAD_1/Component library/Dip_ic_on_sip_socket/models3d/DIP/DIP-8 on SCSL-4 x2.step
10.2 x 10.2 x 10.9 mm
SCSL x 2
DIP

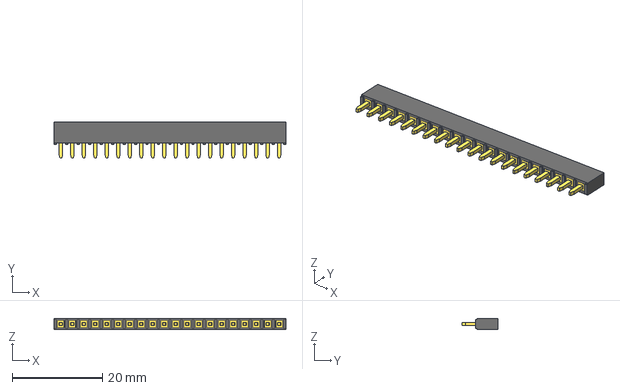
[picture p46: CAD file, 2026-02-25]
KiCad/KiCAD_1/Component library/Pin_header_female_2_54mm/20-Pin Header - Female - 2.54mm.step
51.3 x 8.00 x 2.50 mm

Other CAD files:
KiCad/KiCAD_1/Component library/Dip_ic_on_sip_socket/models3d/DIP/DIP-40-W on SCSL-20 x2.step
KiCad/KiCAD_1/Component library/Pin_header_female_2_54mm/15-Pin Header - Female - 2.54mm.step
KiCad/KiCAD_1/Component library/Dip_ic_on_sip_socket/models3d/DIP/DIP-24 on SCSL-12 x2.step
KiCad/KiCAD_1/Component library/Pin_header_female_2_54mm/13-Pin Header - Female - 2.54mm.step
KiCad/KiCAD_1/Component library/Dip_ic_on_sip_socket/models3d/DIP/DIP-14 on SCSL-7 x2.step
KiCad/KiCAD_1/Component library/Dip_ic_on_sip_socket/models3d/DIP/DIP-20 on SCSL-10 x2.step
KiCad/KiCAD_1/Component library/Dip_ic_on_sip_socket/models3d/DIP/DIP-24-W on SCSL-12 x2.step
KiCad/KiCAD_1/Component library/Dip_ic_on_sip_socket/models3d/DIP/DIP-28-W on SCSL-14 x2.step
KiCad/KiCAD_1/Component library/Dip_ic_on_sip_socket/models3d/DIP/DIP-32-W on SCSL-16 x2.step
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

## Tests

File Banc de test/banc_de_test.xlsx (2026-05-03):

 | Radius compression(mm) | R | DeltaR/Ro (Sensibilité) | Déformation | Ro | e(mm)
 | 22.5 | 779883.93 | -0.6580023818 | 0.01098901099 | 2280378.25 | 0.5
 | 20 | 755442.62 | -0.6687204765 | 0.01234567901
HB | 17.5 | 738493.93 | -0.6761528795 | 0.01408450704 |  |  |  |  |  |  |  | 1000000 | 0.77988393 | 779883.93
 | 15 | 703638 | -0.6914380323 | 0.01639344262 |  |  |  |  |  |  |  |  |  | 755442.62
 | 12.5 | 663682.56 | -0.7089594413 | 0.01960784314 |  |  |  |  |  |  |  |  |  | 738493.93
 |  |  |  |  |  |  |  |  |  |  |  |  |  | 703638
 |  |  |  |  |  |  |  |  |  |  |  |  | 0.66368256 | 663682.56
 | 22.5 | 802758.62 | -0.3289216322 | 0.01098901099 | 1196221.87
 | 20 | 755442.62 | -0.3684761674 | 0.01234567901 |  |  |  |  |  | Sensibility | R^2
2B | 17.5 | 738493.93 | -0.3826446845 | 0.01408450704 |  |  | COMPRESSION |  | HB | -5.8334 | 0.9963 |  | 0.80275862 | 802758.62
 | 15 | 703638 | -0.4117830332 | 0.01639344262 |  |  | Graphite |  | 2B | -12.635 | 0.9629 |  |  | 755442.62
 | 12.5 | 663682.56 | -0.4451843954 | 0.01960784314 |  |  |  |  | 4B | -8.7708 | 0.995 |  |  | 738493.93
 |  |  |  |  |  |  |  |  | 6B | -14.027 | 0.796 |  |  | 703638
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

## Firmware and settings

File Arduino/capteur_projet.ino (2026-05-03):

#include "menu_OLED.h"
#include "digipot.h"

#include <SoftwareSerial.h>

#define rxPin 8
#define txPin 7
SoftwareSerial mySerial(rxPin, txPin);


const float VCC = 5.0;      // voltage at Ardunio 5V line

// Servomotor
#include <Servo.h>
Servo myservo;


// Declare variables for the graphite sensor
const int graphitePin = A0; 
const float R1 = 100200.0;
const float R3 = 100000.0;
const float R5 = 10000.0;

// Declare variables for the flex sensor
const int flexPin = A1;      // Pin connected to voltage divider output
const float R_DIV = 27000.0;  // resistor used to create a voltage divider

unsigned long lastSend = 0;
const unsigned long interval = 100; // 100 ms

static char selected_sensor = ' ';

void setup() {
  Serial.begin(9600);
  pinMode(flexPin, INPUT);
  pinMode(graphitePin, INPUT);

  initDigipot();
  initMenu();

  //Bluetooth
  pinMode(rxPin,INPUT);
  pinMode(txPin,OUTPUT);
  //Servomotor
  myservo.attach(9);

  mySerial.begin(9600);

}
//Servomotor
void applyAngle(int angle) {
  myservo.write(angle);
}
void loop() {
  updateMenu();
  delay(5);
  
  if (Serial.available() > 0 || mySerial.available()) {
    char cmd;
    if (Serial.available() > 0) {
      cmd = Serial.read();
      if (cmd == '\n' || cmd == '\r') {
    return;
  }
    }
    else if (mySerial.available()) {
      cmd = mySerial.read();
    }
    
    Serial.print("MIT sends ");
    Serial.println(cmd);
    if (cmd == 'C') {
      selected_sensor = 'C'; // *************
    }
    else if (cmd == 'G') {
      selected_sensor = 'G'; // graphite sensor***************
    }
    else if (cmd == 'F') {
      selected_sensor = 'F'; // flex sensor***************
    }
    else {
      selected_sensor = ' ';
    }
  
  }
  // Send data according to the selected sensor
  if (millis() - lastSend >= interval) {
      lastSend = millis();
      if (selected_sensor == 'C') {
        int ADCgraphite = analogRead(graphitePin);
    // Convert the analog reading (which goes from 0 - 1023) to a voltage (0 - 5V):
        float Vgraphite = ADCgraphite * VCC / 1023.0;
        float Rgraphite = (1+R3/R2)*R1*(VCC/Vgraphite)-R1-R5;
        mySerial.print(Vgraphite);
        mySerial.print(" ");
        mySerial.println(Rgraphite);
  }
      else if (selected_sensor == 'G') {
        int ADCgraphite = analogRead(graphitePin);
    // Convert the analog reading (which goes from 0 - 1023) to a voltage (0 - 5V):
        float Vgraphite = ADCgraphite * VCC / 1023.0;
        //R2 = 50000.0;
        float Rgraphite = (1+R3/R2)*R1*(VCC/Vgraphite)-R1-R5;
        mySerial.println(Rgraphite);
        Serial.println(Rgraphite);
        Serial.println(Vgraphite);
        selected_sensor = ' ';
      }
      else if (selected_sensor == 'F') {
        int ADCflex = analogRead(flexPin);
        float Vflex = ADCflex * VCC / 1023.0;
        float Rflex = R_DIV * Vflex/(VCC - Vflex);
        mySerial.println(Rflex);
        Serial.println(Rflex);
        selected_sensor = ' ';
  }
  }

}

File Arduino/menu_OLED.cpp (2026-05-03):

#include "menu_OLED.h"
#include "digipot.h"

#include <Wire.h>
#include <Adafruit_SSD1306.h>
#include <Adafruit_GFX.h>

#define OLED_ADDR 0x3C
Adafruit_SSD1306 display(-1);

#define encoderPinA 2   // CLK
#define encoderPinB 4   // DT
#define encoderButton 3  // SW

volatile int encoderPos = 1;

volatile int mainMenuCount = 1;
volatile int servoMenuCount = 1;
volatile int angle = 0;

void applyAngle(int angle);

static void doEncoder();
static void drawMainMenu();
static void drawSubMenuGain();
static void handleButton();
static void drawSubMenuServoMorto();

volatile bool menuChanged = true;
volatile bool isChoosingAngle = false;
volatile bool isApplyingAngle = false;

unsigned long lastClickTime = 0;

enum MenuLevel {
  MAIN_MENU,
  SUB_MENU_GAIN,
  SUB_MENU_SERVOMOTOR
};

volatile MenuLevel menuLevel = MAIN_MENU;

byte lastButtonState = HIGH;

void initMenu() {
  pinMode(encoderPinA, INPUT_PULLUP);
  pinMode(encoderPinB, INPUT_PULLUP);
  pinMode(encoderButton, INPUT_PULLUP);

  display.begin(SSD1306_SWITCHCAPVCC, OLED_ADDR);
  display.display();
  display.clearDisplay();

  attachInterrupt(digitalPinToInterrupt(encoderPinA), doEncoder, RISING);
  applyGain(128);

}

static void doEncoder() {
  if (menuLevel == MAIN_MENU) {
    if (digitalRead(encoderPinA)==HIGH && digitalRead(encoderPinB)==HIGH) {
      if (encoderPos < 2){
        encoderPos++;
        Serial.println(encoderPos);
    }
  } else if (digitalRead(encoderPinA)==HIGH && digitalRead(encoderPinB)==LOW) {
      if (encoderPos > 1){
        encoderPos--;
        Serial.println(encoderPos);
    }
  }
  }
  else if (menuLevel == SUB_MENU_GAIN) {
    if (digitalRead(encoderPinA)==HIGH && digitalRead(encoderPinB)==LOW) {
      if (encoderPos < 128){
        encoderPos++;
    }
  } else if (digitalRead(encoderPinA)==HIGH && digitalRead(encoderPinB)==HIGH) {
      if (encoderPos > 0){
        encoderPos--;
    }
  }
  }
  else {
    if (isChoosingAngle == true){
      if (digitalRead(encoderPinA)==HIGH && digitalRead(encoderPinB)==HIGH) {
        if (angle < 180){
          angle+=5;
    }
  }   else if (digitalRead(encoderPinA)==HIGH && digitalRead(encoderPinB)==LOW) {
        if (angle > 0){
          angle-=5;
    }
  }
    }
    else {
      if (digitalRead(encoderPinA)==HIGH && digitalRead(encoderPinB)==HIGH) {
        if (encoderPos < 2){
           encoderPos++;
    }
  }   else if (digitalRead(encoderPinA)==HIGH && digitalRead(encoderPinB)==LOW) {
        if (encoderPos > 1){
          encoderPos--;
    }
  }
    }
    
  } 

  menuChanged = true; 
  
}

void updateMenu() {
  handleButton();
  if(menuChanged) {
    menuChanged = false;
    display.clearDisplay();
    if (menuLevel == MAIN_MENU) {
      drawMainMenu();
    }
    else if (menuLevel == SUB_MENU_GAIN){
      drawSubMenuGain(); 
    }
    else {
      drawSubMenuServoMorto();
    }
  }  
  display.display();
}

static void drawMainMenu() {
  display.setTextSize(1);
  display.setTextColor(WHITE);

  display.setCursor(0, 0);
  display.println("PROJET CAPTEUR");

  display.setCursor(10, 10);
  display.println("Adjust Gain Level");
  
  display.setCursor(10, 20);
  display.println("Servo Motor");
 
  display.setCursor(0, encoderPos*10);
  display.println(">");
}

static void drawSubMenuGain() {
  display.setTextSize(1);
  display.setTextColor(WHITE);

  display.setCursor(0, 0);
  display.println("ADJUST GAIN LEVEL");

  display.drawRect(0, 10, 128, 10, WHITE);
  display.fillRect(0, 10, 128-encoderPos, 10, WHITE);
  applyGain(encoderPos);

  display.setCursor(0, 25);
  display.println(">");
  display.setCursor(10, 25);
  display.println("BACK");


}

static void drawSubMenuServoMorto() {
  display.setTextSize(1);
  display.setTextColor(WHITE);

  display.setCursor(10, 0);
  if (isApplyingAngle == true) {
    display.println("APPLY an angle:");
    isApplyingAngle == false;
  }
  else if (isChoosingAngle == false) {
    display.println("Choose an angle:");
  }
  else if (isChoosingAngle == true) {
    display.println("CHOOSE AN ANGLE:");
  }
  display.setCursor(110, 0);
  display.println(angle);

  display.setCursor(10, 10);
  display.println("BACK");

  display.setCursor(0, encoderPos*10-10);
  display.println(">");
}

static void handleButton() {
  byte currentButtonState = digitalRead(encoderButton);
  if (lastButtonState == HIGH && currentButtonState == LOW) {
    unsigned long currentTime = millis();
    if (currentTime - lastClickTime < 700) {
      if (menuLevel == SUB_MENU_SERVOMOTOR) {
        encoderPos = 2;
        isChoosingAngle = false;
        isApplyingAngle = false;
      }
    }
    else {
      if (menuLevel == MAIN_MENU) {
        mainMenuCount = encoderPos;
        if (mainMenuCount == 1) {
          encoderPos = 128;//128
          menuLevel = SUB_MENU_GAIN;
      }
        else if (mainMenuCount == 2) {
          menuLevel = SUB_MENU_SERVOMOTOR;
          encoderPos = 1;
      }
    }
      else if (menuLevel == SUB_MENU_GAIN) {
        menuLevel = MAIN_MENU;
       encoderPos = 1;
    }
      else {
        servoMenuCount = encoderPos;
        if (servoMenuCount == 1 ) {
          if (isChoosingAngle == false) {
            isChoosingAngle = true;
        }
          else {
            isApplyingAngle = true;
            applyAngle(angle);
        }
        
      }
        else if (servoMenuCount == 2) {
          menuLevel = MAIN_MENU;
          encoderPos = 2;
      }
    
    }
    }
    lastClickTime = currentTime;
    menuChanged = true;
  } 
  lastButtonState = currentButtonState;

}

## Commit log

2026-02-21 Travail realise au TP
    [10-Pin Header - Female - 2.54mm.step, 11-Pin Header - Female - 2.54mm.step, 12-Pin Header - Female - 2.54mm.step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]
2026-02-24 first change
    [10-Pin Header - Female - 2.54mm.step, 11-Pin Header - Female - 2.54mm.step, 12-Pin Header - Female - 2.54mm.step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]
2026-02-24 VCC track now correctly connected
    Changes to make; VCC to 5V+
    VCC now connected from potentiometer to VCC track; from R3 to
    Servomoteur_VCC
    Potentiomettre_GND is CORRECTLY connected to the ground plane, it's
    kinda hard to see at first look, but closer inspection makes it obvious
    VCC now connects to C4, R4 and U4
    [KiCAD_1.kicad_pcb]
2026-02-25 VCC is now replace for +5V
    Changes to make: Connect to +5V pin, review the ground plane
    [KiCAD_1.kicad_sch]
2026-02-25 PCB updated with VCC to +5V, GND plane connected
    Flex and servomoteur empreintes updated, with the pin numbers
    +5V track moved for spacing
    [KiCAD_1.kicad_pcb, KiCAD_1.kicad_sch]
2026-02-25 final KICAD
    Resolved the errors
    Used a red cable to connect an isolated GND
    Changed directory name to make it relative ${KIPRJMOD}
    [KiCAD_1.kicad_pcb, KiCAD_1.kicad_sch]
2026-04-08 add Arduino files
    [banc_de_test.xlsx]
2026-04-14 update file excel band de test
    [banc_de_test.xlsx]
2026-04-30 writing readme
    [banc_de_test.xlsx]
2026-05-03 1st final version Readme
    [10-Pin Header - Female - 2.54mm.step, 11-Pin Header - Female - 2.54mm.step, 12-Pin Header - Female - 2.54mm.step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]
